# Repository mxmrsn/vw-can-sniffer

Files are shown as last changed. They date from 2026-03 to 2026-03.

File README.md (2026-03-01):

# VW CAN Sniffer

Hardware-agnostic CAN bus sniffer focused on MK7.5 VW GTI, starting with Teensy 4.0 and a UART stream protocol suitable for an ESP32 Wi‑Fi dashboard.

## Scope
- Teensy 4.0 CAN capture
- UART framing protocol for streaming frames to a Wi‑Fi module
- Future STM32H7 custom board

## Current Contents
- `firmware/teensy/teensy_uart_streamer.ino`
- `firmware/teensy/teensy_can_simulator.ino`
- `docs/uart_protocol.md`
- `firmware/esp32/esp32_uart_gateway.ino`

## Hardware (Initial Setup)
- Teensy 4.0
- CAN transceiver (TJA1051T/3 recommended)
- ESP32 module (UART bridge for Wi‑Fi)

### Basic Wiring (Teensy ↔ ESP32)
- `Teensy TX` → `ESP32 RX`
- `Teensy RX` ← `ESP32 TX`
- `GND` ↔ `GND`
- Optional: `Teensy pin 4` → `ESP32 EN` (reset control)
- Optional: `Teensy pin 5` → `ESP32 RST` (soft reset)

### CAN Transceiver (Optional Control)
- Optional: `Teensy pin 20` → TJA1051 `S` (silent/listen‑only control)

### Output Mode + LEDs
- Mode button: `pin 8` (toggle UART/Wi‑Fi vs USB)
- Select button: `pin 9` (toggle CAN silent)
- LEDs: CAN heartbeat `pin 14`, Wi‑Fi active `pin 15`, USB active `pin 16`, silent indicator `pin 21`

## Firmware Notes
- Default UART: `Serial1` @ `921600`
- Default CAN speed: `500000`
- CAN IDs encode extended frames with bit31 set

## System Block Diagram
```
                 CANH/CANL
   ┌──────────────────────────────────────────┐
   │              Bench / Vehicle             │
   └──────────────────────────────────────────┘
                    │
                    │
              ┌──────────┐        UART (3.3V)
              │ TJA1051  │<-------------------------┐
              └──────────┘                          │
                    │ TXD/RXD                       │
                    │                               │
            ┌────────────────┐                      │
            │ Teensy 4.0     │                      │
            │ CAN1 (pins 22/23)                     │
            │ UART -> ESP32  │----------------------┘
            └────────────────┘
                       │ Wi-Fi
                       │
                 ┌──────────┐
                 │  ESP32   │
                 │ Web UI   │
                 └──────────┘
                       │
                       │ HTTP/WS
                       ▼
                 ┌──────────┐
                 │ Browser  │
                 └──────────┘
```

## Wiring Overview (ASCII)
```
Teensy 4.0                          TJA1051T/3                 CAN Bus
-----------                          ----------                 -------
CTX1 (pin 22) ---------------------> TXD
CRX1 (pin 23) <--------------------- RXD
pin 20 ----------------------------> S (silent)
3V3 -------------------------------> VIO
5V  -------------------------------> VCC
GND -------------------------------> GND ---------------------- GND
                                   CANH ---------------------- CANH
                                   CANL ---------------------- CANL

Teensy 4.0                          ESP32 (UART)               Wi-Fi
-----------                          -----------               -----
TX1 (pin 1) ----------------------> RX
RX1 (pin 0) <---------------------- TX
GND ------------------------------> GND                         ~~~

LEDs / Buttons (Teensy 4.0)
LED CAN (pin 14), LED Wi-Fi (pin 15), LED USB (pin 16), LED Silent (pin 21)
Mode button (pin 8), Select button (pin 9)
```

### Test Mode
Enable synthetic frames for bench testing:

```
#define TEST_MODE 1
#define TEST_RATE_HZ 50
```

## Protocol
See `docs/uart_protocol.md` for the UART framing spec.

## USB Capture
Use `tools/usb_dump.py` to read the framed stream from USB and emit CSV.
Requires `pyserial`.

## PCB Docs
See `pcb-teensy-esp32/teensy-esp32-can-sniffer/docs/README.md` for schematic, layout, and 3D captures.

## Next Steps
- ESP32 firmware to host a WebSocket dashboard
- Basic browser UI for live frame display
- STM32H7 hardware plan

## PlatformIO (ESP32)
If you prefer automation, PlatformIO can build and upload the ESP32 firmware and SPIFFS assets.
See `platformio.ini` and `tools/upload_spiffs.sh`.

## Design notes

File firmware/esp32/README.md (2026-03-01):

# ESP32 UART Gateway

This firmware bridges Teensy UART CAN frames to a browser dashboard via WebSocket.

## Dependencies
Install these in Arduino IDE:
- `WebSockets` by Markus Sattler

## Build & Upload
1. Open `firmware/esp32/esp32_uart_gateway.ino`.
2. Select an ESP32 board (e.g., `ESP32 Dev Module`).
3. Set Wi-Fi credentials in the sketch:

```
static const char *WIFI_SSID = "YOUR_SSID";
static const char *WIFI_PASS = "YOUR_PASSWORD";
```

4. Upload to the ESP32.

## Upload Web Assets (SPIFFS)
The HTML/CSS/JS live in `firmware/esp32/data/` and must be uploaded to SPIFFS.

### PlatformIO (Recommended)
1. Install PlatformIO.
2. Run:

```
./tools/upload_spiffs.sh
```

To upload firmware:

```
./tools/upload_esp32.sh
```

To upload both firmware and SPIFFS:

```
./tools/upload_all_esp32.sh
```

### Arduino IDE 2.x
1. Tools → `ESP32 Sketch Data Upload`.
2. This creates and uploads a SPIFFS image.

If the menu item is missing, install the ESP32 filesystem uploader plugin
for your IDE version.

## Wiring
Default UART pins:
- `RX` = GPIO16
- `TX` = GPIO17

Connect:
- `Teensy TX` → `ESP32 RX` (GPIO16)
- `Teensy RX` ← `ESP32 TX` (GPIO17)
- `GND` ↔ `GND`

## Dashboard
Open a browser to the ESP32’s IP address.
- Web UI: `http://<esp32-ip>/`
- WebSocket: `ws://<esp32-ip>:81`

## UI Preview (No Hardware)
You can preview the static UI locally:

```
./tools/preview_ui.sh
```

Then open `http://localhost:8000` in a browser.

The UI will enter a mock data mode automatically if no WebSocket is available.

## Stats
The dashboard shows two kinds of stats:
- `Rx ok / CRC bad / Bytes` from the ESP32 UART parser
- `T rx_ok / T drop` from Teensy status frames (type `0x02`)

## Controls
The UI can send commands to the Teensy:
- Toggle output mode (UART/Wi‑Fi vs USB)
- Toggle CAN silent mode

## Notes
- If STA Wi-Fi connection fails, the ESP32 starts an AP:
  - SSID: `vw-can-sniffer`
  - Password: `canlogger`

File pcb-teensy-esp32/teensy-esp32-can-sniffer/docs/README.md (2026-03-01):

# Teensy + ESP32 CAN Sniffer PCB

This document summarizes the current PCB design and shows the latest schematic, layout, and 3D model captures.

## Overview
This board is a carrier for a Teensy (CAN host) and an ESP32 module (Wi‑Fi gateway), with a CAN transceiver and support circuitry for bench or in‑vehicle CAN sniffing.

## Schematic
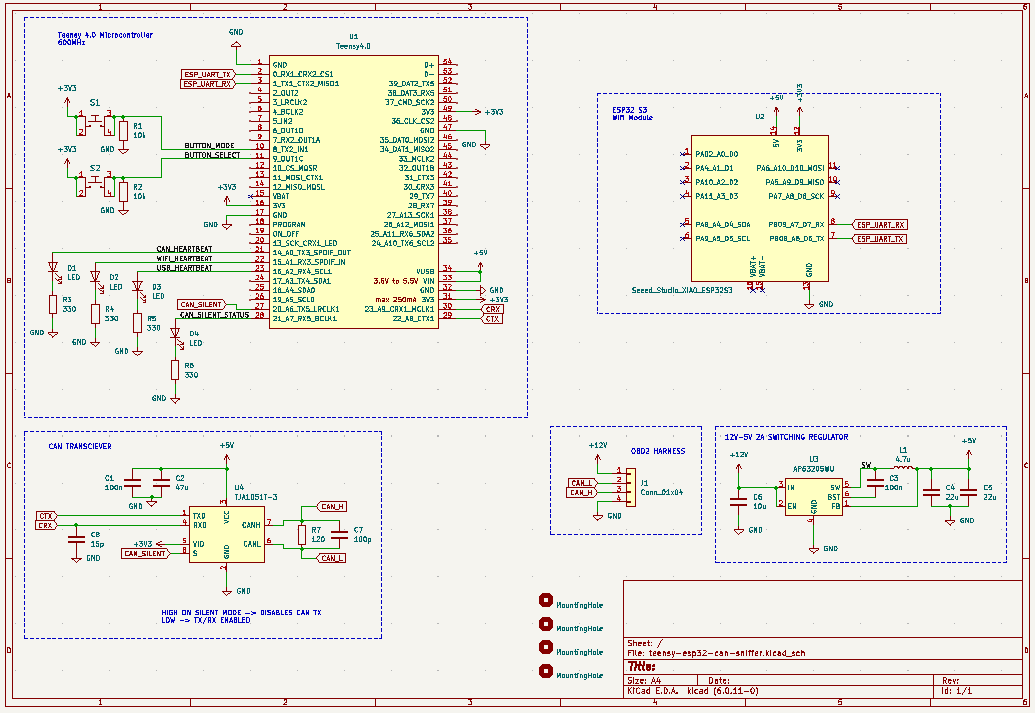
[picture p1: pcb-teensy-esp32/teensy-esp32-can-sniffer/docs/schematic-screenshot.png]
Schematic


## PCB Layout
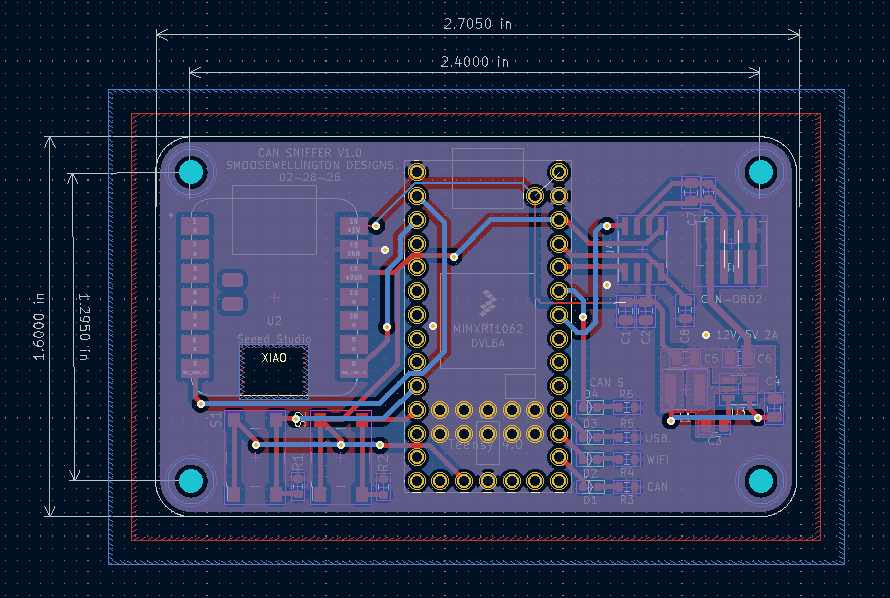
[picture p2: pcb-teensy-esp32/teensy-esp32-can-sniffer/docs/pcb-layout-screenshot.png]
PCB Layout


## 3D Model
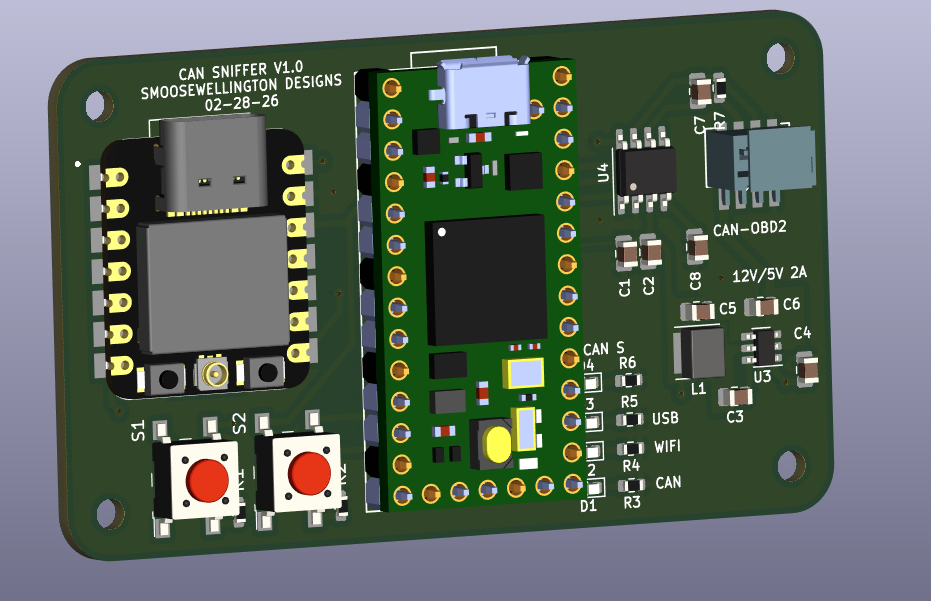
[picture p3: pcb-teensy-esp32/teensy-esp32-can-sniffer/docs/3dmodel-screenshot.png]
3D Model


## Notes
- These images are for documentation and review; update them when the design changes.

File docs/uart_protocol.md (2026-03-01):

# UART CAN Stream Protocol v1

Goal: simple, fixed framing for CAN sniff data over UART.

## Frame Structure
All multi-byte fields are little-endian.

```
[SOF][LEN][TYPE][PAYLOAD...][CRC]

SOF   : 0xA5 (1 byte)
LEN   : payload length in bytes (1 byte, 0-255)
TYPE  : 0x01 = CAN frame (1 byte)
CRC   : 8-bit XOR of [LEN, TYPE, PAYLOAD]
```

### TYPE 0x01 Payload (CAN frame)
```
[timestamp_us(4)][can_id(4)][dlc(1)][data(0-8)]

- timestamp_us: micros() at capture time (wraps ~71 min)
- can_id: 11-bit or 29-bit raw ID (use bit 31 to mark extended)
- dlc: 0-8
```

### CAN ID Encoding
- Standard ID: 0x000007FF max
- Extended ID: set bit31 to 1 and store 29-bit ID in bits 0..28

### TYPE 0x02 Payload (Status)
```
[rx_ok(4)][rx_drop(4)]
```

- `rx_ok`: number of CAN frames received
- `rx_drop`: number of frames dropped due to ring buffer full

### TYPE 0x03 Payload (State)
```
[mode(1)][silent(1)]
```

- `mode`: 0 = UART/Wi‑Fi, 1 = USB
- `silent`: 0 = normal, 1 = silent

### TYPE 0x10 Payload (Command)
```
[cmd(1)][value(1)]
```

Commands (ESP32 → Teensy):
- `0x01`: set output mode (value 0=UART/Wi‑Fi, 1=USB)
- `0x02`: set silent mode (value 0=normal, 1=silent)

### CRC
```
crc = LEN ^ TYPE ^ payload[0] ^ payload[1] ^ ...
```

## Notes
- Stream is byte-oriented; use SOF to resync.
- CRC is simple XOR to keep Teensy/ESP32 code light.
- You can add new message types later (e.g., 0x02 = status).

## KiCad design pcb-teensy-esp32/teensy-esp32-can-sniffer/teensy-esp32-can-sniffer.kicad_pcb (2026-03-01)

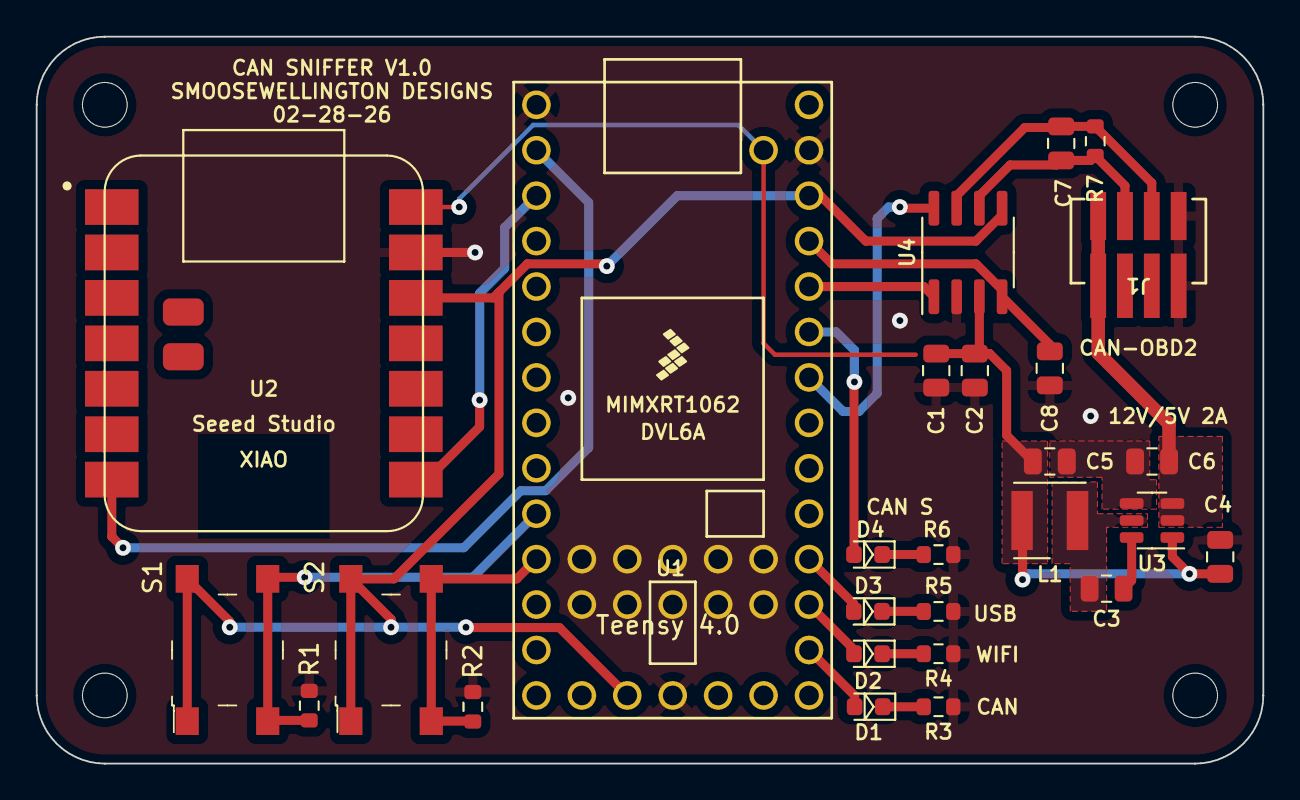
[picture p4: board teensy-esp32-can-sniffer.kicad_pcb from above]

Board: 2 copper layers, 68.6 x 40.6 mm, 31 parts (0 on the bottom side), 23 nets.

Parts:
C1, C3: 100n; C_0805_2012Metric
C2: 47u; C_0805_2012Metric
C4, C5: 22u; C_0805_2012Metric
C6: 10u; C_0805_2012Metric
C7: 100p; C_0805_2012Metric
C8: 15p; C_0805_2012Metric
D1, D2, D3, D4: LED; LED_0603_1608Metric
H1, H2, H3, H4: MountingHole; MountingHole_2.5mm
J1: Conn_01x04; CONN_874370231-SD_04_MOL
L1: 4.7u; L_Wurth_WE-LQSH-4020
R1, R2: 10k; R_0603_1608Metric
R3, R4, R5, R6: 330; R_0603_1608Metric
R7: 120; R_0603_1608Metric
S1, S2: PTS645SM43SMTR92_LFS; Switch_Tactile_SMD_6x6mm_PTS645
U1: Teensy4.0; Teensy40
U2: Seeed_Studio_XIAO_ESP32S3; XIAO-ESP32S3
U3: AP63205WU; TSOT-23-6
U4: TJA1051T-3; SOIC-8_3.9x4.9mm_P1.27mm

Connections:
+3V3: S1.1, S1.2, S2.1, S2.2, U1.16 (3V3), U1.31 (3V3), U2.12 (3V3), U4.5 (VIO)
+5V: C1.1, C2.1, C4.1, C5.1, L1.2, U1.33 (VIN), U1.34 (VUSB), U2.14 (5V), U3.1 (FB), U4.3 (VCC)
+12V: C6.1, J1.1, U3.2 (EN), U3.3 (IN)
/BUTTON_MODE: R1.1, S1.3, S1.4, U1.10 (8_TX2_IN1)
/BUTTON_SELECT: R2.1, S2.3, S2.4, U1.11 (9_OUT1C)
/CAN_HEARTBEAT: D1.2 (A), U1.21 (14_A0_TX3_SPDIF_OUT)
/CAN_SILENT_STATUS: D4.2 (A), U1.28 (21_A7_RX5_BCLK1)
/SW: C3.2, L1.1, U3.5 (SW)
/USB_HEARTBEAT: D3.2 (A), U1.23 (16_A2_RX4_SCL1)
/WIFI_HEARTBEAT: D2.2 (A), U1.22 (15_A1_RX3_SPDIF_IN)
CAN_H: C7.1, J1.3, R7.1, U4.7 (CANH)
CAN_L: C7.2, J1.2, R7.2, U4.6 (CANL)
CAN_SILENT: U1.27 (20_A6_TX5_LRCLK1), U4.8 (S)
CRX: C8.1, U1.30 (23_A9_CRX1_MCLK1), U4.4 (RXD)
CTX: U1.29 (22_A8_CTX1), U4.1 (TXD)
ESP_UART_RX: U1.3 (1_TX1_CTX2_MISO1), U2.8 (PB09_A7_D7_RX)
ESP_UART_TX: U1.2 (0_RX1_CRX2_CS1), U2.7 (PB08_A6_D6_TX)
GND: C1.2, C2.2, C4.2, C5.2, C6.2, C8.2, J1.4, R1.2, R2.2, R3.2, R4.2, R5.2, R6.2, U1.1 (GND), U1.17 (GND), U1.32 (GND), U2.13 (GND), U3.4 (GND), U4.2 (GND)
unnamed: C3.1, U3.6 (BST)
unnamed: D1.1 (K), R3.1
unnamed: D2.1 (K), R4.1
unnamed: D3.1 (K), R5.1
unnamed: D4.1 (K), R6.1

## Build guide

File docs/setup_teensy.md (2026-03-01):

# Teensy Setup

This project uses the Arduino IDE + Teensyduino and the FlexCAN_T4 library.

## Install Tools
1. Install the Arduino IDE.
2. Install Teensyduino (the Teensy installer). It integrates with the Arduino IDE.

## Install FlexCAN_T4
1. Open Arduino IDE.
2. Go to `Sketch` → `Include Library` → `Manage Libraries…`
3. Search for `FlexCAN_T4` and install the latest version.

## Build/Upload
1. Open `firmware/teensy/teensy_uart_streamer.ino`.
2. Select `Tools` → `Board` → `Teensy 4.1`.
3. Select the Teensy serial port under `Tools` → `Port`.
4. Click Upload.

## Notes
- Default CAN speed in the sketch is `500000`.
- Default UART is `Serial1` at `921600`.
- Enable synthetic frames for bench testing by setting `TEST_MODE` to `1`.
- CAN activity LED on `A0 / pin 14` (short pulse on RX).
- Wi‑Fi active LED on `pin 15` (blinks when UART/Wi‑Fi mode selected).
- USB activity LED on `pin 16` (pulses on USB writes).
- CAN silent indicator LED on `pin 21`.
- Mode button on `pin 8` (toggles UART vs USB output).
- Select button on `pin 9` (toggles CAN silent).

When `TEST_MODE` is enabled, a periodic status frame (type `0x02`) is emitted once per second
with `rx_ok` and `rx_drop` counters to validate the framing and transport.

The Teensy also emits a periodic state frame (type `0x03`) with output mode and silent status.

## USB Capture Script
You can capture the USB stream and dump CSV using:

```
python3 tools/usb_dump.py /dev/ttyACM0
```

Requires `pyserial` (e.g., `pip install pyserial`).

## Teensy 4.0 UART Pins (Serial1)
- `TX1 = pin 1`
- `RX1 = pin 0`

## Recommended CAN Transceiver
- `TJA1051T/3` (good availability and 3.3V MCU I/O support via VIO pin)

## TJA1051 Wiring (Typical)
- `VCC` → 5V supply
- `VIO` → 3.3V (Teensy logic)
- `GND` → Ground
- `TXD` → Teensy CAN TX (see explicit pins below)
- `RXD` ← Teensy CAN RX (see explicit pins below)
- `CANH` / `CANL` → CAN bus
- `S` → Teensy `pin 21` (optional silent mode control)

Bench bus termination:
- 120Ω at each end of the CAN bus (not at every node)

## Teensy 4.0 CAN Pins (Explicit)
These are the default CAN pin pairs on Teensy 4.0:
- `CAN1` TX/RX: `CTX1 = pin 22`, `CRX1 = pin 23`
- `CAN2` TX/RX: `CTX2 = pin 1`, `CRX2 = pin 0`
- `CAN3` TX/RX: `CTX3 = pin 31`, `CRX3 = pin 30` (bottom pads)

This project uses `CAN1` in the sketches by default, so wire the transceiver to pins 22/23.

## Wiring Table (Teensy 4.0 CAN1 ↔ TJA1051)
Use this as a quick reference for CAN1:

| TJA1051 Pin | Connects To |
| --- | --- |
| `TXD` | Teensy `CTX1` (pin 22) |
| `RXD` | Teensy `CRX1` (pin 23) |
| `VCC` | 5V |
| `VIO` | 3.3V |
| `GND` | GND |
| `CANH` | CANH |
| `CANL` | CANL |

## Optional ESP32 Reset (Teensy GPIO)
If you want the Teensy to reset the ESP32:
- Teensy `pin 4` → ESP32 `EN`
- Teensy `pin 5` → ESP32 `RST`
- Keep `EN` high for normal operation

Note: `EN` is active‑low; pulling it low resets the ESP32.
Note: `RST` is also active‑low; pulling it low reboots the ESP32 without cutting power.

## Optional TJA1051 Silent Mode
- Teensy `pin 20` → TJA1051 `S`
- `S = LOW` → normal mode
- `S = HIGH` → silent (listen‑only)

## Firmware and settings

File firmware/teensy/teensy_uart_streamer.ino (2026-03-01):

/*
  Teensy 4.0 CAN sniffer -> UART/USB streamer
  Protocol documented in docs/uart_protocol.md

  Dependencies:
  - FlexCAN_T4 (Teensyduino Library Manager)
*/

#include <Arduino.h>
#include <FlexCAN_T4.h>
#include "pins.h"

// ---------- Config ----------
static const uint32_t UART_BAUD = 921600;
static const uint32_t CAN_BAUD  = 500000; // typical VW CAN speed; adjust if needed

// Set to 1 to generate synthetic frames on a timer (bench testing without CAN)
#define TEST_MODE 0
#define TEST_RATE_HZ 50

// UART device (to ESP32)
#define UART_PORT Serial1
// USB serial device (to PC)
#define USB_PORT Serial

// Output mode selection
enum OutputMode : uint8_t { OUTPUT_UART = 0, OUTPUT_USB = 1 };
static OutputMode output_mode = OUTPUT_UART;

// External LEDs
static const uint32_t LED_PULSE_MS = 40;
static const uint32_t LED_WIFI_PERIOD_MS = 500;
static uint32_t led_can_last_ms = 0;
static uint32_t led_usb_last_ms = 0;
static uint32_t led_wifi_last_ms = 0;

// Buttons (active-low with pullups)
static uint32_t last_btn_ms = 0;
static bool last_mode_state = true;
static bool last_select_state = true;

// CAN device (Teensy 4.0 has CAN1/CAN2/CAN3)
FlexCAN_T4<CAN1, RX_SIZE_256, TX_SIZE_16> Can0;

// ---------- Protocol ----------
static const uint8_t SOF  = 0xA5;
static const uint8_t TYPE_CAN = 0x01;
static const uint8_t TYPE_STAT = 0x02;
static const uint8_t TYPE_STATE = 0x03;
static const uint8_t TYPE_CMD = 0x10;

struct CanFrameLite {
  uint32_t ts_us;
  uint32_t id;
  uint8_t  dlc;
  uint8_t  data[8];
};

// ---------- Ring Buffer ----------
static const uint16_t RB_SIZE = 256;
static CanFrameLite rb[RB_SIZE];
static volatile uint16_t rb_head = 0;
static volatile uint16_t rb_tail = 0;

// ---------- Stats ----------
static volatile uint32_t stat_rx_ok = 0;
static volatile uint32_t stat_rx_drop = 0;
static uint32_t stat_last_ms = 0;
static uint32_t state_last_ms = 0;

// ---------- Command Parser ----------
struct CmdParser {
  uint8_t state = 0;
  uint8_t len = 0;
  uint8_t type = 0;
  uint8_t idx = 0;
  uint8_t crc = 0;
  uint8_t payload[32];
} cmd_parser;

static inline bool rb_is_full() {
  return ((rb_head + 1) % RB_SIZE) == rb_tail;
}

static inline bool rb_is_empty() {
  return rb_head == rb_tail;
}

static inline void rb_push(const CanFrameLite &f) {
  if (rb_is_full()) {
    // Drop newest if full (simple policy)
    stat_rx_drop++;
    return;
  }
  rb[rb_head] = f;
  rb_head = (rb_head + 1) % RB_SIZE;
}

static inline bool rb_pop(CanFrameLite &out) {
  if (rb_is_empty()) return false;
  out = rb[rb_tail];
  rb_tail = (rb_tail + 1) % RB_SIZE;
  return true;
}

// ---------- Helpers ----------
static inline uint8_t xor_crc(const uint8_t *buf, size_t len) {
  uint8_t c = 0;
  for (size_t i = 0; i < len; i++) c ^= buf[i];
  return c;
}

static inline uint32_t encode_can_id(const CAN_message_t &msg) {
  if (msg.flags.extended) {
    return (0x80000000u | (msg.id & 0x1FFFFFFFu));
  }
  return (msg.id & 0x7FFu);
}

static void set_output_mode(OutputMode mode) {
  output_mode = mode;
  USB_PORT.printf("Output mode: %s\n", output_mode == OUTPUT_UART ? "UART" : "USB");
}

static void set_silent_mode(bool silent) {
  digitalWrite(CAN_SILENT_PIN, silent ? HIGH : LOW);
}

static void send_frame(uint8_t type, const uint8_t *payload, uint8_t len) {
  uint8_t header[3] = { SOF, len, type };
  uint8_t crc = len ^ type ^ xor_crc(payload, len);

  if (output_mode == OUTPUT_UART) {
    UART_PORT.write(header, sizeof(header));
    UART_PORT.write(payload, len);
    UART_PORT.write(&crc, 1);
  } else {
    USB_PORT.write(header, sizeof(header));
    USB_PORT.write(payload, len);
    USB_PORT.write(&crc, 1);
    digitalWrite(LED_USB_PIN, HIGH);
    led_usb_last_ms = millis();
  }
}

static void handle_cmd(const uint8_t *payload, uint8_t len) {
  if (len < 2) return;
  uint8_t cmd = payload[0];
  uint8_t val = payload[1];

  switch (cmd) {
    case 0x01: // set output mode
      if (val <= 1) {
        set_output_mode(val == 0 ? OUTPUT_UART : OUTPUT_USB);
      }
      break;
    case 0x02: // set silent
      set_silent_mode(val != 0);
      break;
    default:
      break;
  }
}

static void cmd_parser_feed(uint8_t b) {
  switch (cmd_parser.state) {
    case 0:
      if (b == SOF) cmd_parser.state = 1;
      break;
    case 1:
      cmd_parser.len = b;
      cmd_parser.crc = b;
      cmd_parser.state = 2;
      break;
    case 2:
      cmd_parser.type = b;
      cmd_parser.crc ^= b;
      cmd_parser.idx = 0;
      if (cmd_parser.len > sizeof(cmd_parser.payload)) {
        cmd_parser.state = 0;
      } else if (cmd_parser.len == 0) {
        cmd_parser.state = 4;
      } else {
        cmd_parser.state = 3;
      }
      break;
    case 3:
      cmd_parser.payload[cmd_parser.idx++] = b;
      cmd_parser.crc ^= b;
      if (cmd_parser.idx >= cmd_parser.len) cmd_parser.state = 4;
      break;
    case 4:
      if (cmd_parser.crc == b) {
        if (cmd_parser.type == TYPE_CMD) {
          handle_cmd(cmd_parser.payload, cmd_parser.len);
        }
      }
      cmd_parser.state = 0;
      break;
    default:
      cmd_parser.state = 0;
      break;
  }
}

void setup() {
  UART_PORT.begin(UART_BAUD);
  USB_PORT.begin(115200);
  while (!UART_PORT && millis() < 2000) {}

  pinMode(CAN_SILENT_PIN, OUTPUT);
  digitalWrite(CAN_SILENT_PIN, LOW); // normal mode (LOW = normal, HIGH = silent)

  pinMode(LED_CAN_PIN, OUTPUT);
  pinMode(LED_WIFI_PIN, OUTPUT);
  pinMode(LED_USB_PIN, OUTPUT);
  pinMode(LED_SILENT_PIN, OUTPUT);
  digitalWrite(LED_CAN_PIN, LOW);
  digitalWrite(LED_WIFI_PIN, HIGH);
  digitalWrite(LED_USB_PIN, LOW);
  digitalWrite(LED_SILENT_PIN, LOW);

  pinMode(BTN_MODE_PIN, INPUT_PULLUP);
  pinMode(BTN_SELECT_PIN, INPUT_PULLUP);

  Can0.begin();
  Can0.setBaudRate(CAN_BAUD);
  Can0.setMaxMB(16);
  Can0.enableFIFO();
  Can0.enableFIFOInterrupt();
  Can0.onReceive([](const CAN_message_t &msg){
    CanFrameLite f;
    f.ts_us = micros();
    f.id = encode_can_id(msg);
    f.dlc = msg.len;
    for (uint8_t i = 0; i < msg.len; i++) f.data[i] = msg.buf[i];
    rb_push(f);
    stat_rx_ok++;

    // CAN activity pulse
    digitalWrite(LED_CAN_PIN, HIGH);
    led_can_last_ms = millis();
  });
}

void loop() {
  uint32_t now_ms = millis();

  // Mode button (toggle output)
  bool mode_state = digitalRead(BTN_MODE_PIN);
  bool select_state = digitalRead(BTN_SELECT_PIN);
  if (now_ms - last_btn_ms > 50) {
    if (last_mode_state && !mode_state) {
      set_output_mode(output_mode == OUTPUT_UART ? OUTPUT_USB : OUTPUT_UART);
      last_btn_ms = now_ms;
    }
    if (last_select_state && !select_state) {
      set_silent_mode(digitalRead(CAN_SILENT_PIN) == LOW);
      last_btn_ms = now_ms;
    }
  }
  last_mode_state = mode_state;
  last_select_state = select_state;

  // LEDs
  if (led_can_last_ms && now_ms - led_can_last_ms >= LED_PULSE_MS) {
    digitalWrite(LED_CAN_PIN, LOW);
    led_can_last_ms = 0;
  }
  if (led_usb_last_ms && now_ms - led_usb_last_ms >= LED_PULSE_MS) {
    digitalWrite(LED_USB_PIN, LOW);
    led_usb_last_ms = 0;
  }
  if (output_mode == OUTPUT_UART) {
    if (now_ms - led_wifi_last_ms >= LED_WIFI_PERIOD_MS) {
      led_wifi_last_ms = now_ms;
      digitalWrite(LED_WIFI_PIN, !digitalRead(LED_WIFI_PIN));
    }
  } else {
    digitalWrite(LED_WIFI_PIN, LOW);
  }
  digitalWrite(LED_SILENT_PIN, digitalRead(CAN_SILENT_PIN) ? HIGH : LOW);

  // Periodic status frame (TEST_MODE only)
#if TEST_MODE
  if (now_ms - stat_last_ms >= 1000) {
    stat_last_ms = now_ms;
    uint8_t payload[8];
    memcpy(&payload[0], &stat_rx_ok, 4);
    memcpy(&payload[4], &stat_rx_drop, 4);
    send_frame(TYPE_STAT, payload, 8);
  }
#endif

  // Periodic state frame (always)
  if (now_ms - state_last_ms >= 1000) {
    state_last_ms = now_ms;
    uint8_t payload[2];
    payload[0] = (uint8_t)output_mode;
    payload[1] = digitalRead(CAN_SILENT_PIN) ? 1 : 0;
    send_frame(TYPE_STATE, payload, 2);
  }

  // Handle incoming commands from ESP32 over UART
  while (UART_PORT.available()) {
    cmd_parser_feed((uint8_t)UART_PORT.read());
  }

  // Synthetic frame generator for bench testing
#if TEST_MODE
  static uint32_t last_us = 0;
  uint32_t now = micros();
  if ((uint32_t)(now - last_us) >= (1000000u / TEST_RATE_HZ)) {
    last_us = now;
    CanFrameLite f;
    f.ts_us = now;
    f.id = 0x123;
    f.dlc = 8;
    for (uint8_t i = 0; i < f.dlc; i++) f.data[i] = (uint8_t)(now >> (i * 2));
    rb_push(f);
  }
#endif

  // Drain UART as fast as possible
  CanFrameLite f;
  while (rb_pop(f)) {
    uint8_t payload[4 + 4 + 1 + 8];
    size_t idx = 0;

    // timestamp
    memcpy(&payload[idx], &f.ts_us, 4); idx += 4;
    // can id
    memcpy(&payload[idx], &f.id, 4); idx += 4;
    // dlc
    payload[idx++] = f.dlc;
    // data
    memcpy(&payload[idx], f.data, f.dlc); idx += f.dlc;

    uint8_t len = (uint8_t)idx;
    uint8_t header[3] = { SOF, len, TYPE_CAN };
    uint8_t crc = len ^ TYPE_CAN ^ xor_crc(payload, len);

    if (output_mode == OUTPUT_UART) {
      UART_PORT.write(header, sizeof(header));
      UART_PORT.write(payload, len);
      UART_PORT.write(&crc, 1);
    } else {
      USB_PORT.write(header, sizeof(header));
      USB_PORT.write(payload, len);
      USB_PORT.write(&crc, 1);
      digitalWrite(LED_USB_PIN, HIGH);
      led_usb_last_ms = millis();
    }
  }

  // Yield to background tasks
  yield();
}

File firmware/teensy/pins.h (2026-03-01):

#pragma once

// Output pins
#define LED_CAN_PIN 14     // CAN activity
#define LED_WIFI_PIN 15    // UART/Wi-Fi active
#define LED_USB_PIN 16     // USB activity
#define LED_SILENT_PIN 21  // CAN silent indicator

// Buttons (active-low with pullups)
#define BTN_MODE_PIN 8
#define BTN_SELECT_PIN 9

// CAN transceiver silent mode (Teensy pin 20 -> TJA1051 S)
#define CAN_SILENT_PIN 20

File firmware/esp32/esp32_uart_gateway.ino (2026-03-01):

/*
  ESP32 UART -> WebSocket gateway for Teensy CAN stream
  Protocol: docs/uart_protocol.md

  Dependencies (Arduino Library Manager):
  - WebSockets ("WebSockets by Markus Sattler")

  Works with the built-in WebServer from ESP32 core and SPIFFS.
*/

#include <Arduino.h>
#include <WiFi.h>
#include <WebServer.h>
#include <WebSocketsServer.h>
#include <SPIFFS.h>

// ---------- Wi-Fi Config ----------
static const char *WIFI_SSID = "YOUR_SSID";
static const char *WIFI_PASS = "YOUR_PASSWORD";

// If STA fails, start AP for quick access
static const bool ENABLE_SOFTAP_FALLBACK = true;
static const char *AP_SSID = "vw-can-sniffer";
static const char *AP_PASS = "canlogger"; // >= 8 chars

// ---------- UART Config ----------
static const uint32_t UART_BAUD = 921600;
#define UART_PORT Serial2
static const int UART_RX_PIN = 16;
static const int UART_TX_PIN = 17;

// ---------- Protocol ----------
static const uint8_t SOF = 0xA5;
static const uint8_t TYPE_CAN = 0x01;
static const uint8_t TYPE_STAT = 0x02;
static const uint8_t TYPE_STATE = 0x03;
static const uint8_t TYPE_CMD = 0x10;

// ---------- Servers ----------
WebServer http(80);
WebSocketsServer ws(81);

// ---------- LED ----------
static const int LED_PIN = LED_BUILTIN;
static const uint32_t LED_PERIOD_MS = 500;
static uint32_t led_last_ms = 0;


// ---------- UART Parser ----------
struct Parser {
  uint8_t state = 0;
  uint8_t len = 0;
  uint8_t type = 0;
  uint8_t idx = 0;
  uint8_t crc = 0;
  uint8_t payload[32];
} parser;

// ---------- Stats ----------
static uint32_t stat_rx_ok = 0;
static uint32_t stat_rx_bad = 0;
static uint32_t stat_bytes = 0;
static uint32_t stat_last_ms = 0;

static inline uint8_t xor_crc(const uint8_t *buf, size_t len) {
  uint8_t c = 0;
  for (size_t i = 0; i < len; i++) c ^= buf[i];
  return c;
}

static void handle_can_payload(const uint8_t *p, uint8_t len) {
  if (len < 9) return; // ts(4)+id(4)+dlc(1)
  stat_rx_ok++;

  uint32_t ts = 0, id = 0;
  memcpy(&ts, p, 4);
  memcpy(&id, p + 4, 4);
  uint8_t dlc = p[8];
  if (dlc > 8) dlc = 8;

  char data_hex[3 * 8 + 1];
  data_hex[0] = '\0';
  for (uint8_t i = 0; i < dlc; i++) {
    char tmp[4];
    snprintf(tmp, sizeof(tmp), "%02X ", p[9 + i]);
    strncat(data_hex, tmp, sizeof(data_hex) - strlen(data_hex) - 1);
  }

  // JSON message
  char out[160];
  snprintf(out, sizeof(out), "{\"ts\":%lu,\"id\":%lu,\"dlc\":%u,\"data\":\"%s\"}",
           (unsigned long)ts, (unsigned long)id, (unsigned)dlc, data_hex);
  ws.broadcastTXT(out);
}

static void handle_stat_payload(const uint8_t *p, uint8_t len) {
  if (len < 8) return;
  uint32_t rx_ok = 0, rx_drop = 0;
  memcpy(&rx_ok, p, 4);
  memcpy(&rx_drop, p + 4, 4);

  char out[128];
  snprintf(out, sizeof(out), "{\"type\":\"tstat\",\"rx_ok\":%lu,\"rx_drop\":%lu}",
           (unsigned long)rx_ok, (unsigned long)rx_drop);
  ws.broadcastTXT(out);
}

static void handle_state_payload(const uint8_t *p, uint8_t len) {
  if (len < 2) return;
  uint8_t mode = p[0];
  uint8_t silent = p[1];
  char out[128];
  snprintf(out, sizeof(out), "{\"type\":\"state\",\"mode\":%u,\"silent\":%u}",
           (unsigned)mode, (unsigned)silent);
  ws.broadcastTXT(out);
}

static void send_cmd(uint8_t cmd, uint8_t value) {
  uint8_t payload[2] = { cmd, value };
  uint8_t len = 2;
  uint8_t header[3] = { SOF, len, TYPE_CMD };
  uint8_t crc = len ^ TYPE_CMD ^ xor_crc(payload, len);
  UART_PORT.write(header, sizeof(header));
  UART_PORT.write(payload, len);
  UART_PORT.write(&crc, 1);
}

static int parse_value(const char *s) {
  const char *v = strstr(s, "\"value\"");
  if (!v) return -1;
  v = strchr(v, ':');
  if (!v) return -1;
  return atoi(v + 1);
}

static void parser_feed(uint8_t b) {
  stat_bytes++;
  switch (parser.state) {
    case 0: // wait SOF
      if (b == SOF) { parser.state = 1; }
      break;
    case 1: // LEN
      parser.len = b;
      parser.crc = b;
      parser.state = 2;
      break;
    case 2: // TYPE
      parser.type = b;
      parser.crc ^= b;
      parser.idx = 0;
      if (parser.len > sizeof(parser.payload)) {
        parser.state = 0; // invalid
      } else if (parser.len == 0) {
        parser.state = 4; // CRC next
      } else {
        parser.state = 3; // payload
      }
      break;
    case 3: // PAYLOAD
      parser.payload[parser.idx++] = b;
      parser.crc ^= b;
      if (parser.idx >= parser.len) parser.state = 4;
      break;
    case 4: // CRC
      if (parser.crc == b) {
        if (parser.type == TYPE_CAN) {
          handle_can_payload(parser.payload, parser.len);
        } else if (parser.type == TYPE_STAT) {
          handle_stat_payload(parser.payload, parser.len);
        } else if (parser.type == TYPE_STATE) {
          handle_state_payload(parser.payload, parser.len);
        }
      } else {
        stat_rx_bad++;
      }
      parser.state = 0;
      break;
    default:
      parser.state = 0;
      break;
  }
}

// ---------- Web Handlers ----------
static void setup_static_routes() {
  http.serveStatic("/", SPIFFS, "/index.html");
  http.serveStatic("/app.css", SPIFFS, "/app.css");
  http.serveStatic("/app.js", SPIFFS, "/app.js");
}

void setup() {
  Serial.begin(115200);
  UART_PORT.begin(UART_BAUD, SERIAL_8N1, UART_RX_PIN, UART_TX_PIN);

  pinMode(LED_PIN, OUTPUT);
  digitalWrite(LED_PIN, LOW);

  if (!SPIFFS.begin(true)) {
    // If this fails, the web UI won't load; UART/WebSocket still works.
    Serial.println("SPIFFS mount failed");
  }

  WiFi.mode(WIFI_STA);
  WiFi.begin(WIFI_SSID, WIFI_PASS);
  uint32_t start = millis();
  while (WiFi.status() != WL_CONNECTED && millis() - start < 8000) {
    delay(100);
  }

  if (WiFi.status() != WL_CONNECTED && ENABLE_SOFTAP_FALLBACK) {
    WiFi.mode(WIFI_AP);
    WiFi.softAP(AP_SSID, AP_PASS);
  }

  setup_static_routes();
  http.begin();

  ws.begin();
  ws.onEvent([](uint8_t num, WStype_t type, uint8_t *payload, size_t length) {
    (void)num;
    if (type == WStype_CONNECTED) {
      return;
    }
    if (type == WStype_TEXT) {
      char buf[128];
      size_t n = length < sizeof(buf) - 1 ? length : sizeof(buf) - 1;
      memcpy(buf, payload, n);
      buf[n] = '\0';
      int val = parse_value(buf);
      if (strstr(buf, "set_mode") && val >= 0) {
        send_cmd(0x01, (uint8_t)val);
      } else if (strstr(buf, "set_silent") && val >= 0) {
        send_cmd(0x02, (uint8_t)val);
      }
    }
  });
}
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

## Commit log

2026-02-28 Add README and Teensy setup guide
2026-02-28 Serve ESP32 UI from SPIFFS
2026-02-28 Add ESP32 upload scripts
2026-02-28 Add ESP32 heartbeat and stats
2026-02-28 Add Teensy CAN simulator
2026-02-28 Add TJA1051 wiring notes
2026-02-28 Document Teensy 4.1 CAN pins
2026-02-28 Add CAN1 wiring table
2026-02-28 Improve dashboard with filters and stats
2026-02-28 Add Teensy-controlled ESP32 reset
    [teensy_uart_streamer.ino]
2026-02-28 Add Teensy control of ESP32 RST
2026-02-28 Pulse ESP32 RST on boot
2026-02-28 Add Teensy heartbeat LED
2026-03-01 Add gitignore for PCB artifacts
    [teensy-esp32-can-sniffer.kicad_pcb, teensy-esp32-can-sniffer.kicad_sch]
2026-03-01 Ignore and untrack KiCad backups
2026-03-01 Add Teensy output mode switch and LEDs
2026-03-01 Add PCB doc with screenshots
2026-03-01 Link PCB docs in README
2026-03-01 Blink Wi-Fi LED in UART mode
2026-03-01 Add Teensy pins header and status frames
2026-03-01 Add status frames to dashboard and USB dump tool
2026-03-01 Add wiring overview diagram
2026-03-01 Add UI control commands and state frames
2026-03-01 Add UI labels and update PCB assets
    [teensy-esp32-can-sniffer.kicad_pcb, teensy-esp32-can-sniffer.kicad_sch]
2026-03-01 Fix filter interaction
2026-03-01 Make filters re-render immediately
